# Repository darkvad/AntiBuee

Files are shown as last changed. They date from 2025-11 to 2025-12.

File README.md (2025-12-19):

Système de régulation d'un anneau chauffant Celestron (type C8) à base d'un arduino nano (V3)
=============================================================================================

Ce projet est libre d'utilisation pour un usage privé mais aucune utilisation dans un but commercial n'est permise.
-------------------------------------------------------------------------------------------------------------------

Ce projet à pour but d'assurer la régulation en température des anneaux chauffants Celestron en urilisant leur sonde de température intégrée.
La sonde de température est une thermistance NTC10K et au vu des temépratures de fonctionnement visées (plutot en hiver), les formules de type steinhart simplifiées ne sont pas adaptées car souvent fournies pour une plage de température entre 25°C et 85°C
On utilisera donc la formule de steinhart-hart valable sur toute plage de température et nécessitant les 3 coefficents A , B et C.
 https://fr.wikipedia.org/wiki/Relation_de_Steinhart-Hart
Cette page wikipédia fournit un code python permettant à partir de 3 mesures de référence de déterminer vos coefficients.
Pour mon anneau :

#define COEFA -0.0005832612868399646

#define COEFB 0.0004757002048313418

#define COEFC -5.705419094644155e-07

A vérifier avec votre matériel.

> [!IMPORTANT]
> Le montage produit de la chaleur et donc, le BME280 mis à l'intérieur du boitier risque d'avoir ses mesures de température et d'huumidité faussées.
> Je conseille de le déporter avec un cablage à l'extérieur et loin d'une source de chaleur

La régulation est faite avec un aservissement PID fournissant une sortie PMW afin d'attaquer un module MOSFET pour faire varier la puissance de chauffe de la résistance de l'anneau.
Les paramètres de l'asservissement PID sont à renseigner dans celle lige de code :

double Kp=80, Ki=2, Kd=5;

Le montage doit être alimenté en 12V (pour l'anneau chauffant) et du coup, un "buck converter" est utilisé pour l'alimentation 5V de l'arduino nano, evitant de devoir brancher l'usb en dehors de la programmation / debug.

Voici le schema :

Schematic_ArduDewRing_2025-01-04

Le PCB :
ATTENTION : Le PCB utilise un buck converter Pin inverted ce qui n'est pas forcément le cas de celui que vous aurez et qui n'était pas le cas du mien. Du coup la sérigraphie du PCB est à inverser (Out est en fait In et In est Out). J'ai réglé ce soucis avec mon buck converter en soudant les pins dessous, ce qui m'a permis de le monter comme sur l'emplacement sérigraphié pour ne pas qu'il dépasse du PCB. Vérifiez vos tension avant de souder ou mettre les composants.

PCB_PCB_ArduDewRing_2025-01-04

Les fichiers Gerber :

[Gerber_ArduDewRing_PCB_ArduDewRing_2025-01-04.zip](https://github.com/user-attachments/files/18311245/Gerber_ArduDewRing_PCB_ArduDewRing_2025-01-04.zip)

La liste des composants :

1 Arduino nano V3 par exemple https://fr.aliexpress.com/item/1005007539665675.html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

1 Buck Converter 5V ici : https://fr.aliexpress.com/item/33017156248.html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

1 résistance 10 K ohms

1 ecran OLED SSD1306 en blanc au cas où vous vouliez mettre un film rouge dessus : https://fr.aliexpress.com/item/1005006373062872.html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

Option Film rouge : https://fr.aliexpress.com/item/1005005637966631.html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

1 Driver Mosfet 15A : https://www.amazon.fr/dp/B0BWY5B2P9?ref=ppx_yo2ov_dt_b_fed_asin_title

1 capteur de temp/hum BME 280 : https://www.amazon.fr/temp%C3%A9rature-dhumidit%C3%A9-num%C3%A9rique-pr%C3%A9cision-Interface/dp/B0DP8S6YV2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

1 Connecteur alim 12v par exemple https://fr.aliexpress.com/item/1005007404274787.html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

1 Connecteur jack 3,5 (ou 2.5 si vous avez la rallonge male male 2.5 - 2.5) par exemple https://www.amazon.fr/dp/B01MTNOEOT?ref=ppx_yo2ov_dt_b_fed_asin_title&th=1

1 Connecteur RCA comme ceux ci : https://www.amazon.fr/dp/B09TPL4TV5?ref=ppx_yo2ov_dt_b_fed_asin_title

PS : Les liens correspondent à ce que j'avais en stock de commandes passées ou ce que j'ai commandé pour l'occasion. Ils sont à titre indicatif , achetez où bon vous semble ;)

Les fichiers stl pour un boitier en impression 3D sont dispo dans le dossier 3D_Case. J'y aussi mis les fichiers openscad si vous voulez revoir certains détails.

Et une photo du prototype ... A ce jour, j'attend les PCB, le projet est tout neuf mais testé sur platine d'essai.



Voila les photos du montage (perso je préfère mettre des supports  pour les composants afin de pouvoir les changer facilement en cas de problème, surtout sur les premières versions) :

montage1
montage2
montage3
montage4
montage5
montage6
montage7

Et la mise en boite :






Ce projet est libre d'utilisation pour un usage privé mais aucune utilisation dans un but commercial n'est permise.

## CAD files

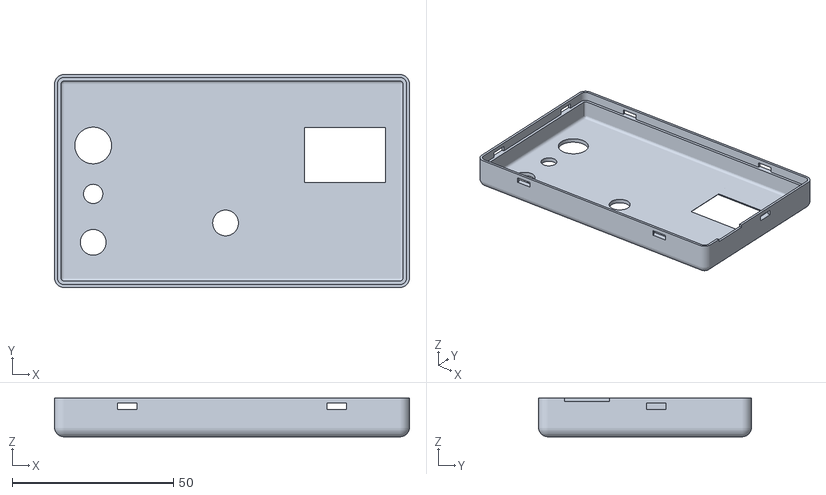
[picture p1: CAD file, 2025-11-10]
3D_Case/Heater_lid.stl
110.0 x 66.0 x 12.0

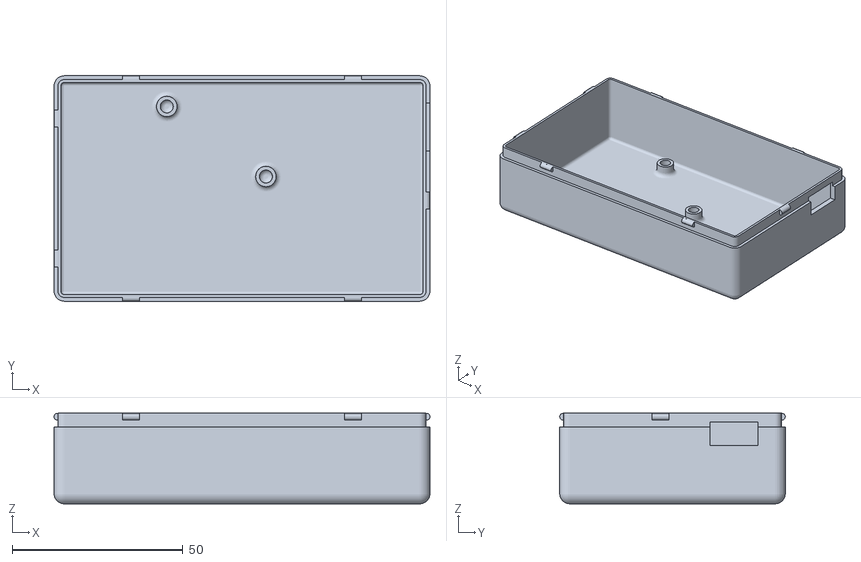
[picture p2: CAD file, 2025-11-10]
3D_Case/Heater_base.stl
110.0 x 66.0 x 26.5

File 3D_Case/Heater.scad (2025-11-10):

/*
***************************************************************************  
**  Yet Another Parameterised Projectbox generator
**
*/

Version="v3.1.2 (2024-04-12)";

/*
**
**  Copyright (c) 2021, 2022, 2023, 2024 Willem Aandewiel
**
**  With help from:
**   - Keith Hadley (parameterized label depth)
**   - Oliver Grafe (connectorsPCB)
**   - Juan Jose Chong (dynamic standoff flange)
**   - Dan Drum (cleanup code)
**   - Dave Rosenhauer (fillets and a lot more)
**
**
**  for many or complex cutouts you might need to adjust
**  the number of elements:
**
**      Preferences->Advanced->Turn off rendering at 250000 elements
**                                                  ^^^^^^
**
**  TERMS OF USE: MIT License. See base offile.
***************************************************************************      
*/

// If set to true will generate the sample box at every save
debug = false;
printMessages = debug;

//---------------------------------------------------------
// This design is parameterized based on the size of a PCB.
//---------------------------------------------------------
// Note: length/lengte refers to X axis, 
//       width/breedte to Y, 
//       height/hoogte to Z

/*
      padding-back|<------pcb length --->|<padding-front
                            RIGHT
        0    X-axis ---> 
        +----------------------------------------+   ---
        |                                        |    ^
        |                                        |   padding-right 
      Y |                                        |    v
      | |    -5,y +----------------------+       |   ---              
 B    a |         | 0,y              x,y |       |     ^              F
 A    x |         |                      |       |     |              R
 C    i |         |                      |       |     | pcb width    O
 K    s |         |                      |       |     |              N
        |         | 0,0              x,0 |       |     v              T
      ^ |    -5,0 +----------------------+       |   ---
      | |                                        |    padding-left
      0 +----------------------------------------+   ---
        0    X-as --->
                          LEFT
*/

//-- which part(s) do you want to print?
printBaseShell        = true;
printLidShell         = true;
printSwitchExtenders  = true;
printDisplayClips     = true;
shiftLid              = 10;  // Set the distance between the lid and base when rendered or previewed side by side
                            
//-- padding between pcb and inside wall
paddingFront        = 1;
paddingBack         = 1;
paddingRight        = 1;
paddingLeft         = 1;

// ********************************************************************
// The Following will be used as the first element in the pbc array

//Defined here so you can define the "Main" PCB using these if wanted
pcbLength           = 120; // front to back (X axis)
pcbWidth            = 50; // side to side (Y axis)
pcbThickness        = 1.6;
standoffHeight      = 1.0;  //-- How much the PCB needs to be raised from the base to leave room for solderings 
standoffDiameter    = 7;
standoffPinDiameter = 2.4;
standoffHoleSlack   = 0.4;

//===================================================================
// *** PCBs ***
// Printed Circuit Boards
//-------------------------------------------------------------------
//  Default origin =  yappCoordPCB : yappCoordBoxInside[0,0,0]
//
//  Parameters:
//   Required:
//    p(0) = name
//    p(1) = length
//    p(2) = width
//    p(3) = posx
//    p(4) = posy
//    p(5) = Thickness
//    p(6) = standoff_Height
//    p(7) = standoff_Diameter
//    p(8) = standoff_PinDiameter
//   Optional:
//    p(9) = standoff_HoleSlack (default to 0.4)

//The following can be used to get PCB values. If "PCB Name" is omitted then "Main" is used
//  pcbLength           --> pcbLength("PCB Name")
//  pcbWidth            --> pcbWidth("PCB Name")
//  pcbThickness        --> pcbThickness("PCB Name") 
//  standoffHeight      --> standoffHeight("PCB Name") 
//  standoffDiameter    --> standoffDiameter("PCB Name") 
//  standoffPinDiameter --> standoffPinDiameter("PCB Name") 
//  standoffHoleSlack   --> standoffHoleSlack("PCB Name") 

pcb = 
[
  //-- Default Main PCB - DO NOT REMOVE the "Main" line.
  ["Main",              pcbLength,pcbWidth,    0,0,    pcbThickness,  standoffHeight, standoffDiameter, standoffPinDiameter, standoffHoleSlack]
];

//-------------------------------------------------------------------

//-- Edit these parameters for your own box dimensions
wallThickness       = 2.0;
basePlaneThickness  = 1.5;
lidPlaneThickness   = 1.5;

//-- Total height of box = lidPlaneThickness 
//                       + lidWallHeight 
//                       + baseWallHeight 
//                       + basePlaneThickness
//-- space between pcb and lidPlane :=
//--      (bottonWallHeight+lidWallHeight) - (standoff_Height+pcb_Thickness)
baseWallHeight      = 10;
lidWallHeight       = 10;

//-- ridge where base and lid off box can overlap
//-- Make sure this isn't less than lidWallHeight 
//     or 1.8x wallThickness if using snaps
ridgeHeight         = 5.0;
ridgeSlack          = 0.3;

//-- Radius of the shell corners
roundRadius         = wallThickness + 1;

//---------------------------
//--     MISC Options     --
//---------------------------

//-- Cone aperture in degrees for countersunk-head screws
countersinkAngle = 90;          //-- metric: 90

// Set the layer height of your printer
printerLayerHeight  = 0.2;

// Set the ratio between the wall thickness and the ridge height. 
//    Recommended to be left at 1.8 but for strong snaps.
wallToRidgeRatio = 1.8;

//---------------------------
//--     C O N T R O L     --
//---------------------------
// -- Render --
renderQuality             = 8;          //-> from 1 to 32, Default = 8

// --Preview --
previewQuality            = 5;          //-> from 1 to 32, Default = 5
showSideBySide            = true;       //-> Default = true
onLidGap                  = 0;  // tip don't override to animate the lid opening
//onLidGap                  = ((ridgeHeight) - (ridgeHeight * abs(($t-0.5)*2)))*2;  // tip don't override to animate the lid opening/closing
colorLid                  = "YellowGreen";   
alphaLid                  = 1;
colorBase                 = "BurlyWood";
alphaBase                 = 1;
hideLidWalls              = false;      //-> Remove the walls from the lid : only if preview and showSideBySide=true 
hideBaseWalls             = false;      //-> Remove the walls from the base : only if preview and showSideBySide=true  
showOrientation           = true;       //-> Show the Front/Back/Left/Right labels : only in preview
showPCB                   = false;      //-> Show the PCB in red : only in preview 
showSwitches              = false;      //-> Show the switches (for pushbuttons) : only in preview 
showButtonsDepressed      = false;      //-> Should the buttons in the Lid On view be in the pressed position
showOriginCoordBox        = false;      //-> Shows red bars representing the origin for yappCoordBox : only in preview 
showOriginCoordBoxInside  = false;      //-> Shows blue bars representing the origin for yappCoordBoxInside : only in preview 
showOriginCoordPCB        = false;      //-> Shows blue bars representing the origin for yappCoordBoxInside : only in preview 
showMarkersPCB            = false;      //-> Shows black bars corners of the PCB : only in preview 
showMarkersCenter         = false;      //-> Shows magenta bars along the centers of all faces  
inspectX                  = 0;          //-> 0=none (>0 from Back)
inspectY                  = 0;          //-> 0=none (>0 from Right)
inspectZ                  = 0;          //-> 0=none (>0 from Bottom)
inspectXfromBack          = true;       //-> View from the inspection cut foreward
inspectYfromLeft          = true;       //-> View from the inspection cut to the right
inspectZfromBottom        = true;       //-> View from the inspection cut up
//---------------------------
//--     C O N T R O L     --
//---------------------------

// ******************************
//  REMOVE BELOW FROM TEMPLATE

// Set the glogal for the quality
facetCount = $preview ? previewQuality*4 : renderQuality*4;

//-- better leave these ----------
buttonWall          = 2.0;
buttonPlateThickness= 2.5;
buttonSlack         = 0.25;

//-- constants, do not change (shifted to large negative values so another element in the 
//-- array won't match

// Define some alternates to undef
yappDefault             = undef;
default                 = undef;

// Shapes
yappRectangle           = -30000;
yappCircle              = -30001;
yappPolygon             = -30002;
yappRoundedRect         = -30003;
yappCircleWithFlats     = -30004;
yappCircleWithKey       = -30005;
yappRing                = -30006;
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

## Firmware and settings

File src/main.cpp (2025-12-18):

#include <Arduino.h>
#include <Wire.h>
#include <EEPROM.h>
#include <Adafruit_Sensor.h>
#include <Adafruit_BME280.h>
#include <Adafruit_GFX.h>
#include <Adafruit_SSD1306.h>
#include <PID_v1.h>
#include <math.h>
#include "order.h"
#include "slave.h"


const unsigned char logo [576] PROGMEM = {
	// 'pngegg, 66x64px
	0x00, 0x00, 0x00, 0x01, 0xe0, 0x00, 0x00, 0x00, 0x00, 0x00, 0x00, 0x00, 0x3d, 0xef, 0x00, 0x00, 
	0x00, 0x00, 0x00, 0x00, 0x01, 0xfd, 0xef, 0xe0, 0x00, 0x00, 0x00, 0x00, 0x00, 0x07, 0xfd, 0xef, 
	0xf8, 0x00, 0x00, 0x00, 0x00, 0x00, 0x0f, 0xfd, 0xef, 0xfc, 0x00, 0x00, 0x00, 0x00, 0x00, 0x1f, 
	0xfd, 0xef, 0xfe, 0x00, 0x00, 0x00, 0x00, 0x00, 0x3f, 0xfd, 0xef, 0xff, 0x00, 0x00, 0x00, 0x00, 
	0x00, 0x7f, 0xfd, 0xef, 0xff, 0x80, 0x00, 0x00, 0x00, 0x00, 0x7f, 0xfd, 0xef, 0xff, 0x80, 0x00, 
	0x00, 0x00, 0x00, 0xff, 0xfd, 0xef, 0xff, 0xc0, 0x00, 0x00, 0x00, 0x00, 0xff, 0xfd, 0xef, 0xff, 
	0xc0, 0x00, 0x00, 0x00, 0x01, 0xff, 0xfd, 0xef, 0xff, 0xc0, 0x00, 0x00, 0x00, 0x01, 0xff, 0xfd, 
	0xef, 0xff, 0xe0, 0x00, 0x00, 0x00, 0x01, 0xff, 0xfd, 0xef, 0xff, 0xe0, 0x00, 0x00, 0x00, 0x01, 
	0xff, 0xfd, 0xef, 0xff, 0xe0, 0x00, 0x00, 0x00, 0x01, 0xff, 0xfd, 0xef, 0xff, 0xe0, 0x00, 0x00, 
	0x00, 0x03, 0xff, 0xfd, 0xef, 0xff, 0xf0, 0x00, 0x00, 0x00, 0x03, 0xff, 0xfd, 0xef, 0xff, 0xf0, 
	0x00, 0x00, 0x00, 0x03, 0xff, 0xfd, 0xef, 0xff, 0xf0, 0x00, 0x00, 0x00, 0x03, 0xff, 0xfd, 0xff, 
	0xff, 0xf0, 0x00, 0x00, 0x00, 0x03, 0xff, 0xff, 0xff, 0xff, 0xf0, 0x00, 0x00, 0x00, 0x03, 0xff, 
	0xff, 0xff, 0xff, 0xf0, 0x00, 0x00, 0x00, 0x03, 0xff, 0xff, 0xff, 0xff, 0xf0, 0x00, 0x00, 0x00, 
	0x03, 0xff, 0xff, 0xff, 0xff, 0xf0, 0x00, 0x00, 0x00, 0x07, 0xff, 0xff, 0xff, 0xff, 0xf8, 0x00, 
	0x00, 0x00, 0x07, 0xff, 0xff, 0xff, 0xff, 0xf8, 0x00, 0x00, 0x00, 0x07, 0xf8, 0x7f, 0xff, 0x87, 
	0xf8, 0x00, 0x00, 0x00, 0x0f, 0xdf, 0xdf, 0xfe, 0xfe, 0xfc, 0x00, 0x00, 0x00, 0x0f, 0x7f, 0xff, 
	0xff, 0xff, 0xbc, 0x00, 0x00, 0x00, 0x1f, 0xff, 0xff, 0xff, 0xff, 0xfe, 0x00, 0x00, 0x00, 0x3f, 
	0xe0, 0xff, 0xff, 0xc1, 0xff, 0x00, 0x00, 0x00, 0x3f, 0xb8, 0x3f, 0xff, 0x07, 0x7f, 0x00, 0x00, 
	0x00, 0x7f, 0x70, 0x1f, 0xfe, 0x03, 0xbf, 0x80, 0x00, 0x00, 0xfe, 0xe0, 0x0f, 0xfc, 0x01, 0xdf, 
	0xc0, 0x00, 0x00, 0xfd, 0xe0, 0x07, 0xf8, 0x01, 0xef, 0xc0, 0x00, 0x01, 0xfb, 0xe0, 0x03, 0xf0, 
	0x01, 0xf7, 0xe0, 0x00, 0x03, 0xff, 0xf8, 0x05, 0xe8, 0x07, 0xff, 0xf0, 0x00, 0x03, 0xf7, 0xff, 
	0x07, 0x38, 0x3f, 0xfb, 0xf0, 0x00, 0x07, 0xef, 0xef, 0xff, 0xff, 0xff, 0xfd, 0xf8, 0x00, 0x07, 
	0xef, 0xf3, 0xfe, 0x1f, 0xf3, 0xfd, 0xf8, 0x00, 0x0f, 0xdf, 0xfc, 0x1f, 0x3e, 0x0f, 0xfe, 0xfc, 
	0x00, 0x0f, 0xdf, 0xff, 0xff, 0xff, 0xff, 0xfe, 0xfc, 0x00, 0x1f, 0xdf, 0xff, 0xff, 0xff, 0xff, 
	0xfe, 0xfe, 0x00, 0x1f, 0xbf, 0xf9, 0xe7, 0xf9, 0xe7, 0xff, 0x7e, 0x00, 0x3f, 0xbf, 0xff, 0xef, 
	0xfd, 0xff, 0xff, 0x7f, 0x00, 0x3f, 0x7f, 0xff, 0xbf, 0x3f, 0x7f, 0xff, 0xbf, 0x00, 0x3f, 0x7f, 
	0xff, 0xfe, 0x1f, 0xff, 0xff, 0xbf, 0x00, 0x7f, 0x7f, 0xff, 0x7e, 0x1f, 0xbf, 0xff, 0xbf, 0x80, 
	0x7e, 0xff, 0xff, 0xfe, 0x1f, 0xff, 0xff, 0xdf, 0x80, 0x7e, 0xff, 0xfe, 0xfc, 0xcf, 0xdf, 0xff, 
	0xdf, 0x80, 0xfe, 0xff, 0xee, 0xfa, 0xd7, 0xdd, 0xff, 0xdf, 0xc0, 0xfd, 0xff, 0xff, 0xf6, 0xdb, 
	0xff, 0xff, 0xef, 0xc0, 0x7d, 0xff, 0xf7, 0xe6, 0xd9, 0xfb, 0xff, 0xef, 0x80, 0x7d, 0xf8, 0x17, 
	0xd6, 0xda, 0xfa, 0x07, 0xef, 0x80, 0x3d, 0x80, 0x17, 0xb6, 0xdb, 0x7a, 0x00, 0x6f, 0x00, 0x1c, 
	0x00, 0x1b, 0x36, 0xdb, 0x36, 0x00, 0x0e, 0x00, 0x08, 0x00, 0x0a, 0x36, 0xdb, 0x14, 0x00, 0x04, 
	0x00, 0x00, 0x00, 0x08, 0x00, 0x00, 0x04, 0x00, 0x00, 0x00, 0x00, 0x00, 0x00, 0xff, 0xff, 0xc0, 
	0x00, 0x00, 0x00, 0x00, 0x00, 0x00, 0x00, 0x00, 0x00, 0x00, 0x00, 0x00, 0x00, 0x00, 0x00, 0x3f, 
	0xff, 0x00, 0x00, 0x00, 0x00, 0x00, 0x00, 0x00, 0x0f, 0xfc, 0x00, 0x00, 0x00, 0x00, 0x00, 0x00, 
	0x00, 0x03, 0xf0, 0x00, 0x00, 0x00, 0x00, 0x00, 0x00, 0x00, 0x00, 0xc0, 0x00, 0x00, 0x00, 0x00
};

// SPDX-FileCopyrightText: 2011 Limor Fried/ladyada for Adafruit Industries
//
// SPDX-License-Identifier: MIT

// Thermistor Example #3 from the Adafruit Learning System guide on Thermistors 
// https://learn.adafruit.com/thermistor/overview by Limor Fried, Adafruit Industries
// MIT License - please keep attribution and consider buying parts from Adafruit

// which analog pin to connect
#define THERMISTORPIN A0
// Pin for top of bridge in order to set it high only when measuring
#define TOPBRIDGE 13         
// resistance at 25 degrees C
#define THERMISTORNOMINAL 10000      
// temp. for nominal resistance (almost always 25 C)
#define TEMPERATURENOMINAL 25   
// how many samples to take and average, more takes longer
// but is more 'smooth'
#define NUMSAMPLES 5
// The beta coefficient of the thermistor (usually 3000-4000)
#define BCOEFFICIENT 3040
// the value of the 'other' resistor
#define SERIESRESISTOR 10000
#define COEFA -0.0005832612868399646
#define COEFB 0.0004757002048313418
#define COEFC -5.705419094644155e-07

// For BME280 sensor, Sea level pressure at your location (used for determinng approx altitude)
#define SEALEVELPRESSURE_HPA (1013.25)
//#define SEALEVELPRESSURE_HPA (1029.00)
#define BMP280_ADDRESS 0x76
#define SCREEN_WIDTH 128 // OLED display width, in pixels
#define SCREEN_HEIGHT 64 // OLED display height, in pixels

// correction de température pour le capteur BME à l'intérieur du boitier
#define deltaTemp 2
#define setOffset 3

// Declaration for an SSD1306 display connected to I2C (SDA, SCL pins)
#define OLED_RESET     -1 // Reset pin # (or -1 if sharing Arduino reset pin)
Adafruit_SSD1306 display(SCREEN_WIDTH, SCREEN_HEIGHT, &Wire, OLED_RESET);

int samples[NUMSAMPLES];
Adafruit_BME280 bme; // I2C
float humidite, temperature, alpha, rosee, pression, altitude;

//Define Variables we'll be connecting PID to
double Setpoint, Input, Output;
// PWM Pin
#define PIN_OUTPUT 11
//Specify the links and initial tuning parameters
double Kp=80, Ki=2, Kd=5;
PID myPID(&Input, &Output, &Setpoint, Kp, Ki, Kd, DIRECT);

bool is_connected = false; ///< True if the connection with the master is available
uint8_t delta_temp = deltaTemp;
uint8_t set_offset = setOffset;
bool is_full = false;
double set_pwm = 0;
float coefa = COEFA;
float coefb = COEFB;
float coefc = COEFC;
const uint8_t tag_eeprom PROGMEM = 0xAB;
uint8_t tag_eeprom_lu = 0x00;

float steinhart = 0.0f;

void save_eeprom () {
  int eeAddress = 0;
  EEPROM.update(eeAddress,tag_eeprom);
  eeAddress+= sizeof(uint16_t);
  EEPROM.put(eeAddress,coefa);
  eeAddress+= sizeof(float);
  EEPROM.put(eeAddress,coefb);
  eeAddress+= sizeof(float);
  EEPROM.put(eeAddress,coefc);
  eeAddress+= sizeof(float);
  EEPROM.put(eeAddress,set_pwm);
  eeAddress+= sizeof(double);
  EEPROM.put(eeAddress,is_full);
  eeAddress+= sizeof(bool);
  EEPROM.update(eeAddress,delta_temp);
  eeAddress+= sizeof(uint8_t);
  EEPROM.update(eeAddress,set_offset);
  eeAddress+= sizeof(uint8_t);

}

void read_eeprom () {
  int eeAddress = 0;
  EEPROM.get(eeAddress,tag_eeprom_lu);
  eeAddress+= sizeof(uint16_t);
  if (tag_eeprom != tag_eeprom_lu) return;
  EEPROM.get(eeAddress,coefa);
  eeAddress+= sizeof(float);
  EEPROM.get(eeAddress,coefb);
  eeAddress+= sizeof(float);
  EEPROM.get(eeAddress,coefc);
  eeAddress+= sizeof(float);
  EEPROM.get(eeAddress,set_pwm);
  eeAddress+= sizeof(double);
  EEPROM.get(eeAddress,is_full);
  eeAddress+= sizeof(bool);
  EEPROM.get(eeAddress,delta_temp);
  eeAddress+= sizeof(uint8_t);
  EEPROM.get(eeAddress,set_offset);
  eeAddress+= sizeof(uint8_t);
}

float steinhart_hart (float Resistance) {
  float temp;
  
  temp = (1 / (coefa + (coefb * log(Resistance)) + (coefc * pow((log(Resistance)),3) ))) - 273.15;

  return temp;
}

void update_delta_temp(uint8_t delta)
{

  delta_temp = delta - 0x30;
//  Serial.println(delta_temp);
}

void update_setpoint_offset(uint8_t offset)
{
  set_offset = offset - 0x30;
//  Serial.println(set_offset);
}

void full()
{
  set_pwm = 255;
  is_full = true;
}

void full(uint16_t mypwm)
{
  set_pwm = mypwm;
  is_full = true;
}

void regul()
{
  set_pwm = 0;
  is_full = false;
}

uint8_t read_i8()
{
	wait_for_bytes(1, 100); // Wait for 1 byte with a timeout of 100 ms
  return (uint8_t) Serial.read();
}

void write_order(enum Order myOrder)
{
	uint8_t* Order = (uint8_t*) &myOrder;
  Serial.write(Order, sizeof(uint8_t));
}


void get_messages_from_serial()
{
  char szF1[8] = "";
  if(Serial.available() > 0)
  {
    // The first byte received is the instruction
    Order order_received = read_order();

    if(order_received == HELLO)
    {
      // If the cards haven't say hello, check the connection
      if(!is_connected)
      {
        is_connected = true;
        write_order(HELLO);
      }
      else
      {
        // If we are already connected do not send "hello" to avoid infinite loop
        write_order(ALREADY_CONNECTED);
      }
    }
    else if(order_received == ALREADY_CONNECTED)
    {
      is_connected = true;
    }
    else
    {
      switch(order_received)
      {
        case FULL:
        {
          full(read_i8());
          break;
        }
        case REGUL:
        {
          regul();
          break;
        }
        case DELTA:
        {
          // between 0 and 20
          update_delta_temp(read_i8());
          break;
        }
        case OFFSET:
        {
          // between 0 and 20
          update_setpoint_offset(read_i8());
          break;
        }
        case STATUS:
        {
          Serial.write("[",1);
          dtostrf( temperature, -2, 2, szF1 );
          Serial.write(szF1,strlen(szF1));
          Serial.write("#",1);
          dtostrf( humidite, -2, 2, szF1 );
          Serial.write(szF1,strlen(szF1));
          Serial.write("#",1);
          dtostrf( steinhart, -2, 2, szF1 );
          Serial.write(szF1,strlen(szF1));
          Serial.write("#",1);
          dtostrf( rosee, -2, 2, szF1 );
          Serial.write(szF1,strlen(szF1));
          Serial.write("#",1);
          dtostrf( Output, -2, 2, szF1 );
          Serial.write(szF1,strlen(szF1));
          Serial.write("#",1);
          itoa(delta_temp, szF1, 10);
          Serial.write(szF1,strlen(szF1));
          Serial.write("#",1);
          itoa(set_offset, szF1, 10);
          Serial.write(szF1,strlen(szF1));
          Serial.write("]",1);

          break;
        }
        case SAVE:
        {
          save_eeprom();
          break;
        }
  			// Unknown order
  			default:
//          Serial.println("ERROR");
          write_order(ERROR);
  				return;
      }
    }
//      Serial.println("RECEIVED");
    write_order(RECEIVED); // Confirm the reception
  }
}


Order read_order()
{
	return (Order) Serial.read();
}

void wait_for_bytes(int num_bytes, unsigned long timeout)
{
	unsigned long startTime = millis();
	//Wait for incoming bytes or exit if timeout
	while ((Serial.available() < num_bytes) && (millis() - startTime < timeout)){}
}

void readValues() {
  temperature = bme.readTemperature();
  temperature = temperature - delta_temp;
  pression = (bme.readPressure() / 100.0F);
  altitude = bme.readAltitude(SEALEVELPRESSURE_HPA);
  humidite = bme.readHumidity();
  
  // calcul du point de rosée (formule de Gustav Magnus-Tetens)
  alpha = log(humidite / 100) + (17.27 * temperature) / (237.3 + temperature);
  rosee = (237.3 * alpha) / (17.27 - alpha);

}

void printValues(float steinhart) {
  if (DEBUG)  {
    Serial.print(F("Température = "));
    Serial.print(temperature);
    Serial.println(F(" *C"));
    
    // Convert temperature to Fahrenheit
    Serial.print(F("Température = "));
    Serial.print(1.8 * temperature + 32);
    Serial.println(F(" *F"));
    
    Serial.print(F("Pression Atm = "));
    Serial.print(pression);
    Serial.println(F(" hPa"));
    
    Serial.print(F("Altitude Approx. = "));
    Serial.print(altitude);
    Serial.println(F(" m"));
    
    Serial.print(F("Humidité = "));
    Serial.print(humidite);
    Serial.println(F(" %"));

    Serial.print(F("Point de rosée = "));
    Serial.print(rosee);
    Serial.println(F(" *C"));

    Serial.println();
  }

  display.clearDisplay();
  display.setTextSize(1);      // Normal 1:1 pixel scale
  display.setTextColor(WHITE); // Draw white text
  display.cp437(true);         // Use full 256 char 'Code Page 437' font
  display.setCursor(0, 0);     // Start at top-left corner
  char buf[32];
  char szF[6];
  dtostrf( temperature, 2, 2, szF );
  sprintf(buf, "Temp Ext : %s C", szF);
  display.println(buf);
  display.setCursor(0, 12);     // Start at top-left corner
  dtostrf( humidite, 2, 2, szF );
  sprintf(buf, "Humidite : %s %%", szF);
  display.println(buf);
  display.setCursor(0, 24);     // Start at top-left corner
  dtostrf( rosee, 2, 2, szF );
  sprintf(buf, "Temp rose : %s C", szF);
  display.println(buf);
  display.setCursor(0, 36);     // Start at top-left corner
  dtostrf( steinhart, 2, 2, szF );
  sprintf(buf, "Temp Tube : %s C", szF);
  display.println(buf);
  display.setCursor(0, 48);     // Start at top-left corner
  dtostrf( Output, 2, 2, szF );
  sprintf(buf, "PWM : %s ", szF);
  display.println(buf);
 
  display.display();
  delay(200);
}

void setup(void) {
  bool status;
  Serial.begin(19200);
  analogReference(EXTERNAL);
  pinMode(TOPBRIDGE, OUTPUT);    // sets the digital pin 13 as output
  digitalWrite(TOPBRIDGE, LOW);
   
  if (DEBUG)  {
    Serial.println(F("Avant Init BME280"));
  }

  status = bme.begin(BMP280_ADDRESS); 
  if (!status) {
    if (DEBUG)  {
      Serial.println(F("Could not find a valid BME280 sensor, check wiring!"));
    }
    while (1);
  }
  // SSD1306_SWITCHCAPVCC = generate display voltage from 3.3V internally
  if(!display.begin(SSD1306_SWITCHCAPVCC, 0x3C)) { 
    if (DEBUG)  {
      Serial.println(F("SSD1306 allocation failed"));
    }
    //for(;;); // Don't proceed, loop forever
  }

  // Show initial display buffer contents on the screen --
  // the library initializes this with an Adafruit splash screen.
  display.clearDisplay();
  display.drawBitmap(31, 0, logo, 66, 64, WHITE);
  display.display();
  delay(4000); // Pause for 2 seconds

  // Clear the buffer
  display.clearDisplay();
  display.setTextSize(1);      // Normal 1:1 pixel scale
  display.setTextColor(WHITE); // Draw white text
  display.setCursor(0, 0);     // Start at top-left corner
  display.cp437(true);         // Use full 256 char 'Code Page 437' font

  display.println(F("Mesure en cours"));
  display.display();

  read_eeprom();
  //initialize the variables we're linked to
  Input = 40;
  Setpoint = 27;

  //turn the PID on
  myPID.SetMode(AUTOMATIC);

  pinMode(PIN_OUTPUT, OUTPUT);

  delay(2000);

}

void loop(void) {
  uint8_t i;
  float average;

  get_messages_from_serial();

  // take N samples in a row, with a slight delay
  digitalWrite(TOPBRIDGE, HIGH); // set top of the resistor bridge to High
  for (i=0; i< NUMSAMPLES; i++) {
   samples[i] = analogRead(THERMISTORPIN);
   delay(10);
  }
  digitalWrite(TOPBRIDGE, LOW); // set top of the resistor bridge to low in order not to heat the thermistor

  // average all the samples out
  average = 0;
  for (i=0; i< NUMSAMPLES; i++) {
     average += samples[i];
  }
  average /= NUMSAMPLES;

  if (DEBUG)  {
    Serial.print(F("Average analog reading ")); 
    Serial.println(average);
  }
  
  // convert the value to resistance
  average = 1023 / average - 1;
  average = SERIESRESISTOR / average;
  if (DEBUG)  {
    Serial.println(F("* Thermistor resistance *")); 
    Serial.println(average);
  }

/*
  steinhart = average / THERMISTORNOMINAL;     // (R/Ro)
  steinhart = log(steinhart);                  // ln(R/Ro)
  steinhart /= BCOEFFICIENT;                   // 1/B * ln(R/Ro)
  steinhart += 1.0 / (TEMPERATURENOMINAL + 273.15); // + (1/To)
  steinhart = 1.0 / steinhart;                 // Invert
  steinhart -= 273.15;                         // convert absolute temp to C
  
  Serial.print(F("Temperature : ")); 
  Serial.print(steinhart);
  Serial.println(" *C");
*/
  steinhart = steinhart_hart(average);
  if (DEBUG)  {
    Serial.print(F("Temperature : ")); 
    Serial.print(steinhart);
    Serial.println(" *C");

    Serial.println(F("* Mesures BME280 *"));
  } 
  readValues();
  Input = steinhart;
  Setpoint = max(rosee + set_offset, temperature);
  if (is_full) {
    Output = set_pwm;
    analogWrite(PIN_OUTPUT, Output);
  } else {
    myPID.Compute();
    analogWrite(PIN_OUTPUT, Output);
  }  


  printValues(steinhart);
  delay(3000);
}

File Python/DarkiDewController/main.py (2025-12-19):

import sys
import os
import serial
import serial.tools.list_ports
from PyQt6.QtWidgets import *
from PyQt6.QtCore import *
from PyQt6.QtGui import *
import pyqtgraph as pg
import numpy as np
from datetime import datetime, timedelta
import threading
import time
import csv
import json
from collections import deque
import logging

# Imports locaux
from protocol import ProtocolHandler, Command
from data_logger import DataLogger
from realtime_plots import RealTimePlot, MultiPlotWidget

class SerialWorker(QObject):
    """Version corrigée avec tous les signaux nécessaires"""
    
    # Tous les signaux requis
    data_received = pyqtSignal(dict)
    status_update = pyqtSignal(str)
    command_ack = pyqtSignal(str, bool)
    raw_data_received = pyqtSignal(bytes)  # Ajouté ici !
    
    def __init__(self):
        super().__init__()
        self.serial_port = None
        self.running = False
        self.baudrate = 19200
        self.protocol = ProtocolHandler()
        self.data_logger = DataLogger()
        
        # États améliorés
        self.awaiting_response = False
        self.current_command = None
        self.response_buffer = bytearray()
        self.status_parsing_state = "WAITING_START"  # WAITING_START, IN_DATA, WAITING_ACK
        
        # Timeout
        self.command_start_time = None
        self.timeout_duration = 10  # 10 secondes par défaut
        
        self.setup_logging()
    
    def setup_logging(self):
        import logging
        self.logger = logging.getLogger('SerialWorker')
        self.logger.setLevel(logging.DEBUG)
        
        handler = logging.FileHandler('serial_corrected.log', mode='w')
        handler.setLevel(logging.DEBUG)
        
        formatter = logging.Formatter(
            '%(asctime)s.%(msecs)03d - STATE:%(state)s - %(message)s',
            datefmt='%H:%M:%S'
        )
        handler.setFormatter(formatter)
        self.logger.addHandler(handler)
        
        self.logger.info("SerialWorker corrigé initialisé", extra={'state': 'INIT'})
    
    def _log_with_state(self, message, level=logging.INFO):
        """Log avec l'état courant"""
        self.logger.log(level, message, extra={'state': self.status_parsing_state})
    
    def connect(self, port, baudrate=19200):
        """Connexion simple"""
        try:
            self.serial_port = serial.Serial(
                port=port,
                baudrate=baudrate,
                timeout=0.1,
                write_timeout=2.0
            )
            self.baudrate = baudrate
            self.running = True
            
            # Démarrer la lecture
            self.read_thread = threading.Thread(target=self.read_data, daemon=True)
            self.read_thread.start()
            
            # Attendre le démarrage puis envoyer HELLO
            threading.Thread(target=self._delayed_startup, daemon=True).start()
            
            self.status_update.emit(f"Connecté à {port}. Attente démarrage...")
            return True
            
        except Exception as e:
            self._log_with_state(f"Erreur connexion: {e}", logging.ERROR)
            self.status_update.emit(f"Erreur: {e}")
            return False
    
    def _delayed_startup(self):
        """Procédure de démarrage avec délai"""
        time.sleep(10)  # Attendre le démarrage du périphérique
        if self.running:
            self._log_with_state("Envoi HELLO après démarrage")
            self.send_hello()
            time.sleep(5.0)
            self._log_with_state("Envoi STATUS après démarrage")
            self.request_status()
    
    def send_hello(self):
        """Envoie HELLO"""
        self._send_command(b'\x30', "HELLO")
    
    def send_delta_temp(self, value):
        """Envoie SET DELTA TEMP"""
        try:
            cmd = self.protocol.create_delta_command(value)
            return self._send_command(cmd, "DELTA")
        except ValueError as e:
            self._log_with_state(f"Erreur DELTA: {e}", logging.ERROR)
            return False
    
    def send_dew_offset(self, value):
        """Envoie SET OFFSET"""
        try:
            cmd = self.protocol.create_offset_command(value)
            return self._send_command(cmd, "OFFSET")
        except ValueError as e:
            self._log_with_state(f"Erreur OFFSET: {e}", logging.ERROR)
            return False
    
    def send_mode(self, is_maxi=True, value=255):
        """Envoie SET MODE"""
        cmd = self.protocol.create_mode_command(is_maxi, value)
        cmd_name = "FULL" if is_maxi else "REGUL"
        self._send_command(cmd, cmd_name)
    
    def request_status(self):
        """Envoie STATUS avec parsing d'état"""
        self._send_command(b'\x38', "STATUS")

    def send_save(self):
        """Envoie SAVE avec parsing d'état"""
        self._send_command(b'\x39', "SAVE")
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

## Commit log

2025-12-17 Gain de memoire
2025-12-18 Mise à jour pour eeprom et valeur pwm
2025-12-18 Fix grammar and clarity issues in README
    Correction de la grammaire et de la clarté dans le README.
2025-12-18 Update README to remove caution regarding MOSFET
    Removed caution about MOSFET module power and PCB tracks.

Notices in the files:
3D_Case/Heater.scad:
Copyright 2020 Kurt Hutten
